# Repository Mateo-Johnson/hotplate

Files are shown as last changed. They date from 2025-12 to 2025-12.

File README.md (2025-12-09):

# Reflow Hot Plate Controller
A custom controller board that turns a cheap aluminum hot plate and heating element into a precision reflow soldering station with PID temperature control and different reflow profiles.

## Finalized Schematic:
Screenshot 2025-12-08 at 11 57 16 AM

## Finalized Layout:
Screenshot 2025-12-08 at 11 56 39 AM

## Finalized Render:
Screenshot 2025-12-08 at 11 56 58 AM

## Finalized Firmware:
A minimal firmware example demonstrating core functionality of the Reflow Hot Plate Controller is available. It initializes SPI thermocouple sensing, runs a basic PID loop to regulate temperature, and drives the MOC3021-triggered TRIAC to control the heating element. This code provides a working control loop at ~10 Hz and serves as a starting point for integrating the touchscreen UI, reflow profiles, and SD logging in later revisions.

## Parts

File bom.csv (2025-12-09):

Reference | Qty | Value | DNP | Exclude from BOM | Exclude from Board | Footprint | Datasheet | Part Number | LCSC Part Number
BZ1 | 1 | Buzzer |  |  |  | Buzzer_Beeper:Buzzer_12x9.5RM7.6 | ~ |  | C64777
C1,C2,C4,C5 | 4 | 4.7u |  |  |  | Capacitor_SMD:C_0402_1005Metric | ~ |  | C23733
C3,C6,C7,C8,C9,C10,C11,C15,C16,C17,C19,C20 | 12 | 100n |  |  |  | Capacitor_SMD:C_0402_1005Metric | ~ |  | C1525
C12,C13 | 2 | 15p |  |  |  | Capacitor_SMD:C_0402_1005Metric | ~ |  | C1548
C14,C18,C21 | 3 | 10u |  |  |  | Capacitor_SMD:C_0805_2012Metric | ~ |  | C15850
C22,C23 | 2 | 100nF |  |  |  | Capacitor_SMD:C_0805_2012Metric | ~ |  | C49678
Card1 | 1 | TF-115 |  |  |  | SDCARD:TF-SMD_TF-115 |  | TF-115 | C91145
D1 | 1 | LTST-C150RKT |  |  |  | LED_SMD:LED_1206_3216Metric | ~ | LTST-C150RKT | C125096
F1 | 1 | Fuse |  |  |  | Fuse:Fuseholder_Cylinder-5x20mm_Stelvio-Kontek_PTF78_Horizontal_Open | ~ |  | C70091
J1 | 1 | USB_C_Receptacle_USB2.0_16P |  |  |  | Connector_USB:USB_C_Receptacle_HCTL_HC-TYPE-C-16P-01A |  | HC-TYPE-C-16P-01A | C2927039
J2 | 1 | Conn_01x02_Pin (Thermocouple) |  |  |  | Connector_JST:JST_PH_S2B-PH-K_1x02_P2.00mm_Horizontal | ~ | S2B-PH-K | C157929
J4 | 1 | Conn_01x08_Pin (TFT Connector) |  |  |  | Connector_PinSocket_2.54mm:PinSocket_1x08_P2.54mm_Vertical | ~ |  | C50981
J5 | 1 | Conn_01x02_Pin (Hot Plate Output) |  |  |  | Connector_Phoenix_MC_HighVoltage:PhoenixContact_MCV_1,5_2-GF-5.08_1x02_P5.08mm_Vertical_ThreadedFlange_MountHole | ~ | MCV 1,5/2-GF-5.08 | C395880
J9 | 1 | Conn_01x02_Pin (AC Input) |  |  |  | Connector_Phoenix_MC_HighVoltage:PhoenixContact_MCV_1,5_2-GF-5.08_1x02_P5.08mm_Vertical_ThreadedFlange_MountHole | ~ | MCV 1,5/2-GF-5.08 | C395880
L1 | 1 | 3.3u |  |  |  | Inductor_SMD:L_0805_2012Metric | ~ |  | C1035
PS1 | 1 | HLK-PM01 |  |  |  | Converter_ACDC:Converter_ACDC_Hi-Link_HLK-PMxx |  | HLK-PM01 | C209900
Q1 | 1 | 2N3904 |  |  |  | Package_TO_SOT_THT:TO-92_Inline |  | 2N3904 | C20526
Q2 | 1 | BTA16-600B |  |  |  | Package_TO_SOT_THT:TO-220-3_Vertical |  | BTA16-600B | C8473
R1,R3,R12,R13,R17,R18,R19,R20,R21 | 9 | 1k |  |  |  | Resistor_SMD:R_0402_1005Metric | ~ |  | C11702
R2 | 1 | 33 |  |  |  | Resistor_SMD:R_0402_1005Metric | ~ |  | C25105
R4,R5 | 2 | RC0402FR-075K1L (5.1kΩ) |  |  |  | 0402:R0402 | ~ | RC0402FR-075K1L | C25905
R6 | 1 | RC0402FR-13220RL (220Ω) |  |  |  | 0402:R0402 | ~ | RC0402FR-13220RL | C25091
R7,R8 | 2 | 27 |  |  |  | Resistor_SMD:R_0402_1005Metric | ~ |  | C25190
R9,R11 | 2 | DNF |  |  |  | Resistor_SMD:R_0402_1005Metric | ~
R10 | 1 | 0 |  |  |  | Resistor_SMD:R_0402_1005Metric | ~ |  | C17168
R14,R15 | 2 | 330Ω |  |  |  | 0402:R0402 | ~ |  | C25104
R16 | 1 | 100Ω |  |  |  | 0402:R0402 | ~ |  | C25076
SW1,SW2 | 2 | SKRKAGE020 |  |  |  | Button_Switch_SMD:SW_Push_SPST_NO_Alps_SKRK | ~ | SKRKAGE020 | C221880
SW3 | 1 | RotaryEncoder_Switch |  |  |  | Rotary_Encoder:RotaryEncoder_Alps_EC11E-Switch_Vertical_H20mm | ~ | EC11E | C370986
U1 | 1 | RP2350_80QFN |  |  |  | Package_DFN_QFN:QFN-80-1EP_10x10mm_P0.4mm_EP3.4x3.4mm_ThermalVias |  | RP2350 | C7473717
U2 | 1 | NCP1117-3.3_SOT223 |  |  |  | Package_TO_SOT_SMD:SOT-223-3_TabPin2 |  | NCP1117-3.3 | C6186
U3 | 1 | W25Q128JVS |  |  |  | Package_SO:SOIC-8_5.3x5.3mm_P1.27mm |  | W25Q128JVS | C97521
U4 | 1 | MOC3021M |  |  |  | Package_DIP:DIP-6_W7.62mm |  | MOC3021M | C24052
U5 | 1 | MAX31855EASA |  |  |  | Package_SO:SOIC-8_3.9x4.9mm_P1.27mm |  | MAX31855EASA | C52036
Y1 | 1 | ABM8-272-T3 |  |  |  | Crystal:Crystal_SMD_3225-4Pin_3.2x2.5mm | ~ | ABM8-272-T3 | C255910

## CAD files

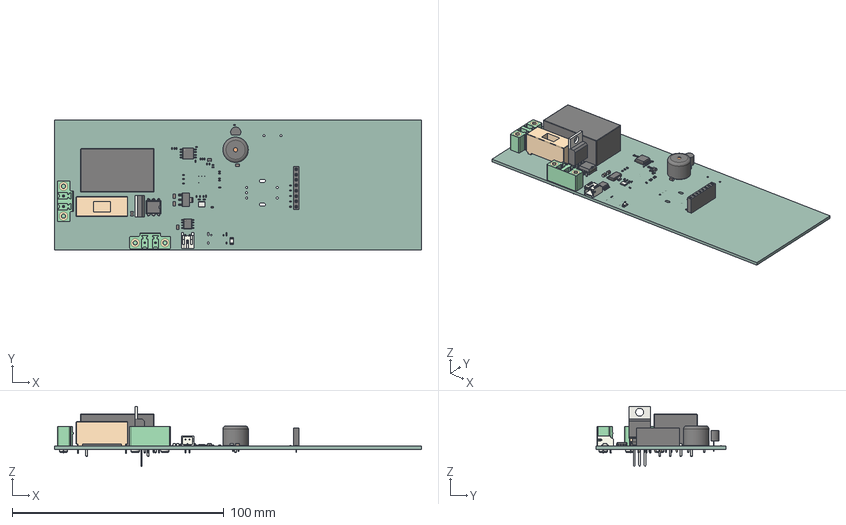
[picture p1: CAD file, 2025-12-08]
PCB/hotplate2.step
173.5 x 61.4 x 28.5 mm
C_0402_1005Metric x 18
TO-220-3_Vertical
PinSocket_1x08_P2.54mm_Vertical
R_0402_1005Metric x 15
C_0805_2012Metric x 5
DIP-6_W7.62mm
Fuseholder_Cylinder-5x20mm_Stelvio-Kontek_PTF78_Horizontal_Open
SOT-223
JST_PH_S2B-PH-K_1x02_P2.00mm_Horizontal
L_0805_2012Metric
Buzzer_12x9.5RM7.6
PhoenixContact_MCV_1,5_2-GF-5.08_1x02_P5.08mm_Vertical_ThreadedFlange_ MountHole x 2
SOIC-8_3.9x4.9mm_P1.27mm
Crystal_SMD_3225-4Pin_3.2x2.5mm
LED_1206_3216Metric
TO-92_Inline
Converter_ACDC_Hi-Link_HLK-PMxx
SOIC-8_5.3x5.3mm_P1.27mm
hotplate2_PCB

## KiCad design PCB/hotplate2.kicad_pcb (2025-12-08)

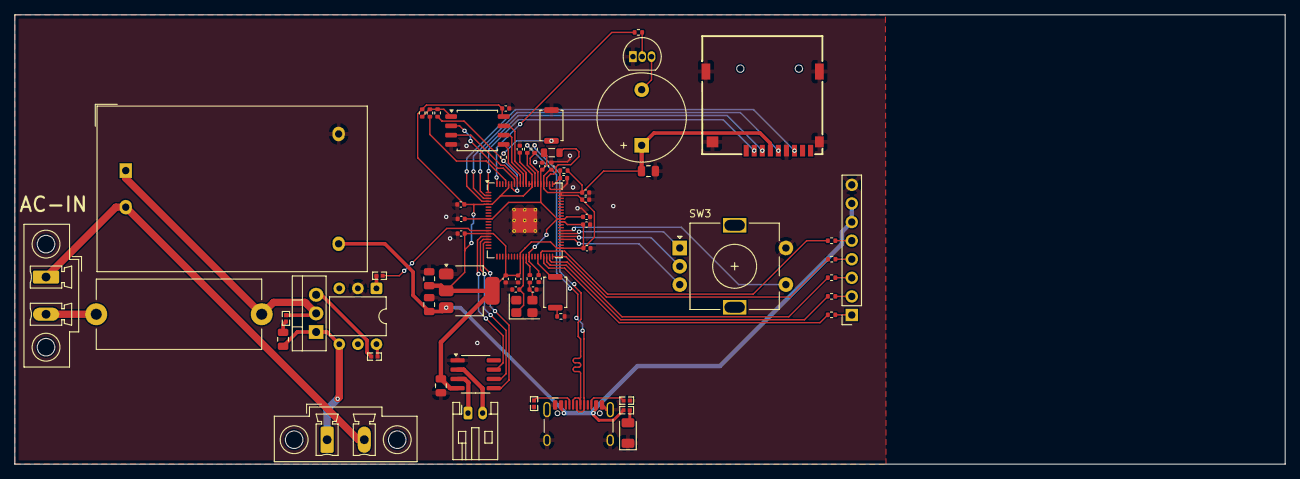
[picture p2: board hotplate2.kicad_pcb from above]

Board: 2 copper layers, 173.5 x 61.4 mm, 66 parts (0 on the bottom side), 62 nets.

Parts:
BZ1: Buzzer; Buzzer_12x9.5RM7.6
C1, C2, C4, C5: 4.7u; C_0402_1005Metric
C3, C6, C7, C8, C9, C10, C11, C15, C16, C17, C19, C20: 100n; C_0402_1005Metric
C12, C13: 15p; C_0402_1005Metric
C14, C18, C21: 10u; C_0805_2012Metric
C22, C23: 100nF; C_0805_2012Metric
Card1: TF-115; TF-SMD_TF-115
D1: LTST-C150RKT; LED_1206_3216Metric
F1: Fuse; Fuseholder_Cylinder-5x20mm_Stelvio-Kontek_PTF78_Horizontal_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
J1: USB_C_Receptacle_USB2.0_16P; USB_C_Receptacle_HCTL_HC-TYPE-C-16P-01A
J2: Conn_01x02_Pin (Thermocouple); JST_PH_S2B-PH-K_1x02_P2.00mm_Horizontal
J4: Conn_01x08_Pin (TFT Connector); PinSocket_1x08_P2.54mm_Vertical
J5: Conn_01x02_Pin (Hot Plate Output); PhoenixContact_MCV_1,5_2-GF-5.08_1x02_P5.08mm_Vertical_Thre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
J9: Conn_01x02_Pin (AC Input); PhoenixContact_MCV_1,5_2-GF-5.08_1x02_P5.08mm_Vertical_Thre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
L1: 3.3u; L_0805_2012Metric
PS1: HLK-PM01; Converter_ACDC_Hi-Link_HLK-PMxx
Q1: 2N3904; TO-92_Inline
Q2: BTA16-600B; TO-220-3_Vertical
R1, R3, R12, R13, R17, R18, R19, R20, R21: 1k; R_0402_1005Metric
R2: 33; R_0402_1005Metric
R4, R5: RC0402FR-075K1L (5.1kΩ); R0402
R6: RC0402FR-13220RL (220Ω); R0402
R7, R8: 27; R_0402_1005Metric
R9, R11: DNF; R_0402_1005Metric
R10: 0; R_0402_1005Metric
R14, R15: 330Ω; R0402
R16: 100Ω; R0402
SW1, SW2: SKRKAGE020; SW_Push_SPST_NO_Alps_SKRK
SW3: RotaryEncoder_Switch; RotaryEncoder_Alps_EC11E-Switch_Vertical_H20mm
U1: RP2350_80QFN; QFN-80-1EP_10x10mm_P0.4mm_EP3.4x3.4mm_ThermalVias
U2: NCP1117-3.3_SOT223; SOT-223-3_TabPin2
U3: W25Q128JVS; SOIC-8_5.3x5.3mm_P1.27mm
U4: MOC3021M; DIP-6_W7.62mm
U5: MAX31855EASA; SOIC-8_3.9x4.9mm_P1.27mm
Y1: ABM8-272-T3; Crystal_SMD_3225-4Pin_3.2x2.5mm

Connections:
+1V1: C2.1, C3.1, C5.1, C6.1, L1.1, U1.10 (DVDD), U1.32 (DVDD), U1.51 (DVDD), U1.65 (VREG_FB)
+3V3: BZ1.1 (+), C1.1, C7.1, C8.1, C9.1, C10.1, C11.1, C15.1, C16.1, C17.1, C18.1, C19.1, C20.1, C21.1, C23.2, Card1.4 (VDD), R2.1, R11.1, U1.5 (IOVDD), U1.15 (IOVDD), U1.24 (IOVDD), U1.29 (IOVDD), U1.41 (IOVDD), U1.50 (IOVDD), U1.59 (ADC_AVDD), U1.60 (IOVDD), U1.64 (VREG_VIN), U1.68 (USB_OTP_VDD), U1.69 (QSPI_IOVDD), U1.76 (IOVDD), U2.2 (VO), U3.8 (VCC), U5.4 (V_{CC})
/01: R21.1, U1.36 (GPIO28)
/02: R20.1, U1.40 (GPIO32)
/03: R19.1, U1.39 (GPIO31)
/04: R18.1, U1.38 (GPIO30)
/05: R17.1, U1.37 (GPIO29)
/FLASH_SS: R9.2, R10.2, R11.2, U3.1 (~CS)
/GPIO0: R9.1, U1.77 (GPIO0)
/GPIO3: R13.2, U1.80 (GPIO3)
/GPIO4: Card1.2 (CD/DAT3), U1.1 (GPIO4)
/GPIO5: Card1.3 (CMD), U1.2 (GPIO5)
/GPIO6: Card1.5 (CLK), U1.3 (GPIO6)
/GPIO7: Card1.7 (DAT0), U1.4 (GPIO7)
/GPIO15: R14.1, U1.14 (GPIO15)
/GPIO16: U1.18 (GPIO18), U5.5 (SCK)
/GPIO17: U1.16 (GPIO16), U5.7 (SO)
/GPIO18: U1.17 (GPIO17), U5.6 (~CS)
/GPIO35: SW3.B, U1.44 (GPIO35)
/GPIO36: SW3.C, U1.45 (GPIO36)
/GPIO37: SW3.A, U1.46 (GPIO37)
/GPIO38: SW3.S1, U1.47 (GPIO38)
/QSPI_SCLK: U1.71 (QSPI_SCLK), U3.6 (CLK)
/QSPI_SD0: U1.72 (QSPI_SD0), U3.5 (DI(IO0))
/QSPI_SD1: U1.74 (QSPI_SD1), U3.2 (DO(IO1))
/QSPI_SD2: U1.73 (QSPI_SD2), U3.3 (IO2)
/QSPI_SD3: U1.70 (QSPI_SD3), U3.7 (IO3)
/QSPI_SS: R3.1, R10.1, U1.75 (QSPI_SS)
/RUN: SW2.2, U1.35 (RUN)
/USB_D+: J1.A6 (D+), J1.B6 (D+), R7.1
/USB_D-: J1.A7 (D-), J1.B7 (D-), R8.1
/VREG_AVDD: C4.1, R2.2, U1.61 (VREG_AVDD)
/VREG_LX: L1.2, U1.63 (VREG_LX)
/XIN: C12.1, U1.30 (XIN), Y1.1
/XOUT: R12.1, U1.31 (XOUT)
/~USB_BOOT: R3.2, SW1.1
AC: F1.1, PS1.1 (AC/L), Q2.2 (A2), R16.1
GND: C1.2, C2.2, C3.2, C4.2, C5.2, C6.2, C7.2, C8.2, C9.2, C10.2, C11.2, C12.2, C13.2, C14.2, C15.2, C16.2, C17.2, C18.2, C19.2, C20.2, C21.2, C23.1, Card1.6 (VSS), Card1.10 (SHELL), Card1.11 (SHELL), Card1.12 (SHELL), Card1.13 (SHELL), D1.1 (K), J1.A1 (GND), J1.A12 (GND), J1.B1 (GND), J1.B12 (GND), J1.S1 (SHIELD), J4.8, PS1.3 (-Vout), Q1.1 (E), R1.2, R4.2, R5.2, SW1.2, SW3.S2, U1.62 (VREG_PGND), U1.81 (GND), U2.1 (GND), U3.4 (GND), U4.2, U5.1 (GND), Y1.2, Y1.4
NEUT: J5.2, J9.1, PS1.2 (AC/N)
unnamed: BZ1.2 (-), Q1.3 (C)
unnamed: C13.1, R12.2, Y1.3
unnamed: C22.1, R16.2
unnamed: D1.2 (A), R6.2
unnamed: J1.A5 (CC1), R4.1
unnamed: J1.B5 (CC2), R5.1
unnamed: J2.1, U5.3 (T+)
unnamed: J2.2, U5.2 (T-)
unnamed: J4.1, R17.2
unnamed: J4.2, R18.2
unnamed: J4.3, R19.2
unnamed: J4.4, R20.2
unnamed: J4.5, R21.2
unnamed: C22.2, J5.1, Q2.1 (A1), U4.4
unnamed: F1.2, J9.2
unnamed: Q1.2 (B), R13.1
unnamed: Q2.3 (G), R15.2
unnamed: R1.1, SW2.1
unnamed: R14.2, U4.1
unnamed: R15.1, U4.6
unnamed: R8.2, U1.66 (USB_DM)
unnamed: R7.2, U1.67 (USB_DP)
VBUS: C14.1, J1.A4 (VBUS), J1.A9 (VBUS), J1.B4 (VBUS), J1.B9 (VBUS), J4.6, J4.7, PS1.4 (+Vout), R6.1, U2.3 (VI)

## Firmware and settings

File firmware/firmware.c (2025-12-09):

#include <stdint.h>
#include <math.h>
#include "hal_spi.h"
#include "hal_gpio.h"
#include "hal_timer.h"

// ---------------------------
// CONFIG
// ---------------------------
#define SPI_PORT        SPI1
#define TC_CS_PIN       GPIO_PIN_5
#define TRIAC_PIN       GPIO_PIN_10

#define LOOP_HZ         10.0f
#define DT              (1.0f / LOOP_HZ)

// PID constants (tune later)
static float Kp = 8.0f;
static float Ki = 0.6f;
static float Kd = 2.0f;

float pid_integral = 0.0f;
float pid_prev_err = 0.0f;

// ---------------------------
// READ THERMOCOUPLE
// MAX31855-style 32-bit word
// ---------------------------
float read_temp_c(void) {
    uint8_t rx[4] = {0};
    hal_gpio_write(TC_CS_PIN, 0);
    hal_spi_rx(SPI_PORT, rx, 4);
    hal_gpio_write(TC_CS_PIN, 1);

    uint32_t v = (rx[0] << 24) | (rx[1] << 16) | (rx[2] << 8) | rx[3];

    if (v & 0x00000007) {
        return NAN;  // Fault bit
    }

    int16_t temp_raw = (v >> 18) & 0x3FFF;
    if (temp_raw & 0x2000) {
        temp_raw |= 0xC000;
    }

    return temp_raw * 0.25f;  // °C
}

// ---------------------------
// SIMPLE PID
// ---------------------------
float pid_step(float set, float meas) {
    float error = set - meas;

    pid_integral += error * DT;
    float deriv = (error - pid_prev_err) / DT;

    pid_prev_err = error;

    float out = Kp * error + Ki * pid_integral + Kd * deriv;
    if (out < 0) out = 0;
    if (out > 1) out = 1;

    return out;
}

// ---------------------------
// TRIAC FIRING (phase angle)
// 0–1 PID output → phase delay
// Lower output = longer delay before firing
// ---------------------------
void triac_fire(float level) {
    float delay_ms = (1.0f - level) * 8.3f; // 8.3 ms → half-cycle at 60 Hz
    hal_timer_delay_ms(delay_ms);
    hal_gpio_write(TRIAC_PIN, 1);
    hal_timer_delay_us(100);    // 100 µs gate pulse
    hal_gpio_write(TRIAC_PIN, 0);
}

// ---------------------------
// MAIN LOOP
// ---------------------------
int main(void) {
    hal_spi_init(SPI_PORT, 1000000);
    hal_gpio_mode(TC_CS_PIN, GPIO_OUTPUT);
    hal_gpio_mode(TRIAC_PIN, GPIO_OUTPUT);
    hal_gpio_write(TRIAC_PIN, 0);

    float setpoint = 180.0f; // test target temp °C

    hal_timer_init();

    while (1) {
        float temp = read_temp_c();
        if (!isnan(temp)) {
            float duty = pid_step(setpoint, temp);
            triac_fire(duty);
        }

        hal_timer_delay_ms((int)(DT * 1000));  // maintain loop rate
    }
}

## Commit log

2025-12-08 Revise README with project details and images
    Updated project title and added detailed descriptions and images for the finalized schematic, layout, and render.
2025-12-09 Add firmware example for Reflow Hot Plate Controller
    Added a minimal firmware example for the Reflow Hot Plate Controller, detailing its core functionality including SPI thermocouple sensing and PID loop operation.
